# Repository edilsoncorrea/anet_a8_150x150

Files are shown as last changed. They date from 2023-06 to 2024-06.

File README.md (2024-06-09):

# anet_a8_150x150
Documentação para a criação da Impressora 3D baseada na Anet A8 de 150mm x 150mm

[Lista de peças](https://docs.google.com/spreadsheets/d/166N1_jKjehIjcxCUM2Ibk8MToJvCky88ICG7slx1OKs/edit#gid=0)

### Pinagem da minha montagem
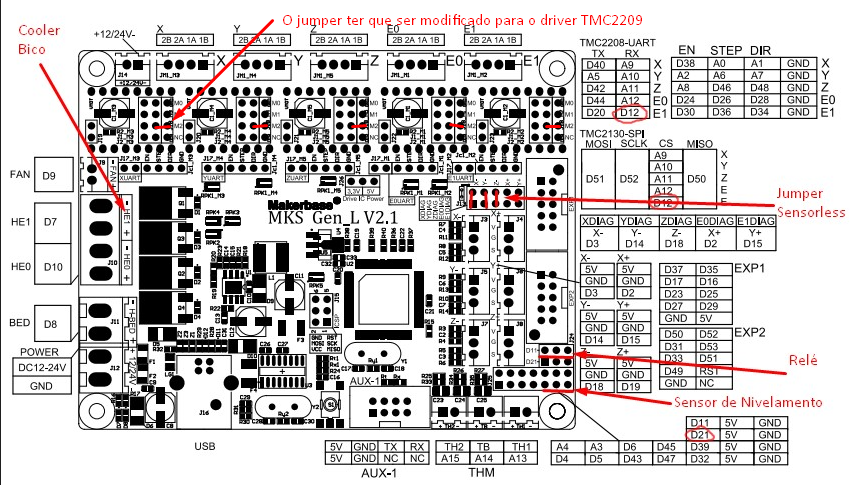
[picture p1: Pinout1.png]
Minha Montagem


Os motores precisarão ser invertidos quando trocar os drivers de DRV8825 para TMC2209

Os motores dos eixos deverão de ajustados para 600mA e o motor da extrusora para 960mA.

[Fork do Marlin para a Anet A8 Mini](https://github.com/edilsondsnerp/Marlin.git)

[MKS Gen L v21](https://github.com/edilsoncorrea/mksgenlv21.git)

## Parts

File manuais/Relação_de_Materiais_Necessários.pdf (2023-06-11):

Relação de Materiais Necessários

Estrutura de Aluminio V-Slot 20x20 | | Ferramentas Necessárias
3 Perfis com 320mm | Furadeira/Parafusadeira | Macho M3x0.5 | Chave Philips
4 Perfis com 350mm | Broca de Aço Rápido 2.5mm | Macho M6x1.0 | Alicate de Corte
8 Parafusos M6x30mm | Broca de Aço Rápido 3.0 mm | Broca de Aço Rápido 6.0 mm | Fita Hellerman
| Broca de Aço Rápido 5.0 mm | Fresa de Aço Rápido 11.0 mm | Chave Allen 3/16
Nome | Qtd de Peças Impressas | Tipo de Parafuso | Tamanho em mm | Qtd de Parafusos | Qtd de Porcas | Qtd de Arruelas
Fim de Curso Z - Base | 1 | M3 | 12 | 2 | 0 | 2
Fim de Curso Z - Móvel | 1 | M3 | 18 | 2 | 2 | 4
Tensionador da Correia Y - Base | 1 | M3 | 18 | 2 | 0 | 2
Tensionador da Correia Y - Móvel | 1 | M3 | 28 | 2 | 2 | 3
Suporte Placa Anet + Mosfet | 1* | M3 | 18 | 3 | 0 | 3
M3 | 8 | 8 | 0 | 0
Suporte Placa Anet | 1* | M3 | 18 | 3 | 0 | 3
| | M3 | 8 | 4 | 0 | 0
Suporte Placa Ramps | 1* | M3 | 18 | 3 | 0 | 3
| | M3 | 8 | 4 | 0 | 0
Suporte Placa Ramps + Mosfet | 1* | M3 | 18 | 3 | 0 | 3
M3 | 8 | 8 | 0 | 0
Base Suporte LCD | 2 | M3 | 18 | 2 | 0 | 2
| | M3 | 12 | 2 | 2 | 2
Suporte LCD Anet | 1* | M3 | 8 | 4 | 0 | 0
Suporte LCD Ramps 2004 SD | 1* | M3 | 8 | 4 | 0 | 0
Suporte Conector Tomada | 1** | M3 | 18 | 2 | 0 | 2
Suporte Motor Y | 1 | M3 | 18 | 2 | 0 | 2
M3 | 8 | 3 | 0 | 3
Suporte Motor Z | 2 | M3 | 18 | 3 | 0 | 3
M3 | 8 | 4 | 0 | 4
Trava Superior Z Esquerda | 1 | M3 | 18 | 2 | 0 | 2
Trava Superior Z Direita | 1 | M3 | 18 | 2 | 0 | 2
Trava Guia Linear Y Direita | 2 | M3 | 18 | 4 | 0 | 4
Trava Guia Linear Y Esquerda | 1 | M3 | 18 | 2 | 0 | 2
Trava Guia Linear Y Fim de Curso | 1 | M3 | 18 | 2 | 0 | 2
Trava da Fonte de Alimentação | 0 | M3 | 18 | 2 | 0 | 0
* - Escolher o modelo e imprimir apenas o correto
Quantidade de Parafusos | | ** - Imprimir apenas se tiver a peça necessária
M6x30mm | 8
M3x8mm | 19 | Peças necessárias que deverão ser compradas por fora
M3x12mm | 4 | 4 x Pézinhos M6 Emborrachados
M3x18mm | 30
M3x28mm | 2
Porcas M3 | 6
Arruelas M3 | 53

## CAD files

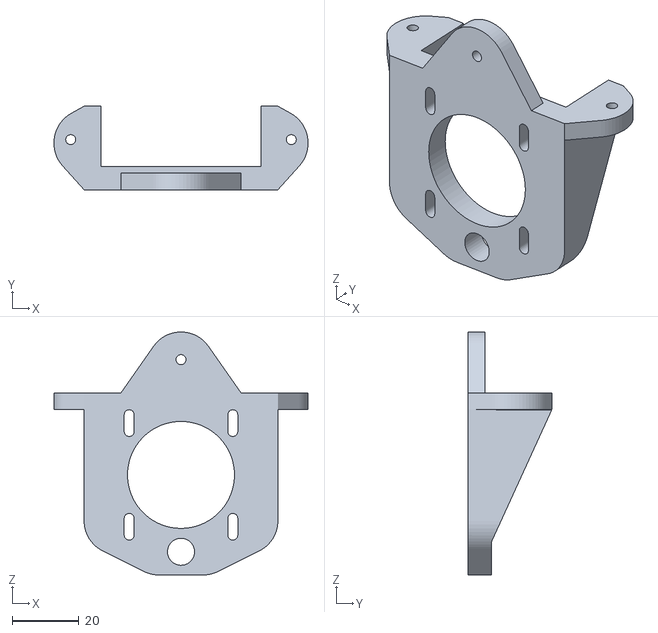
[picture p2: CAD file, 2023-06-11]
stl/Suporte_Motor_Z_v10.stl
76.0 x 25.0 x 72.7

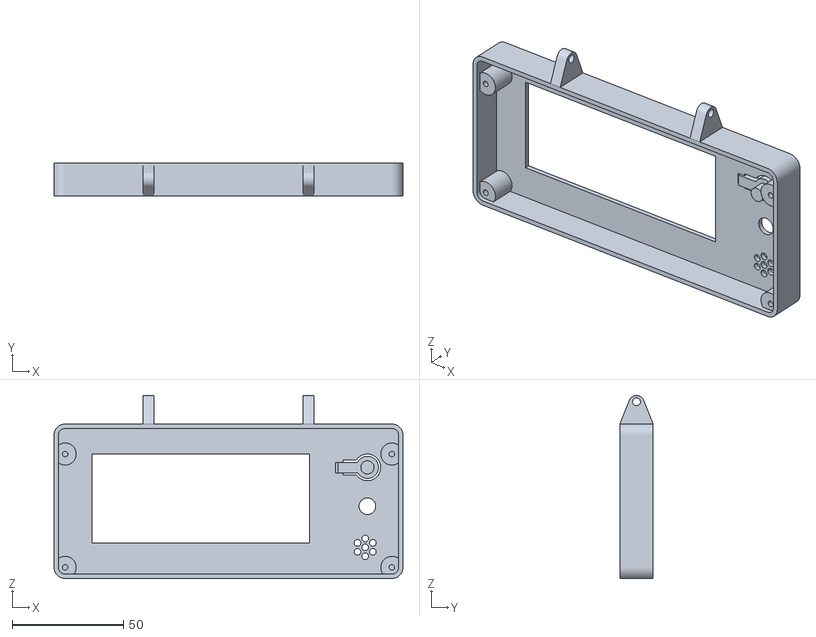
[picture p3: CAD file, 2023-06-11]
stl/Suporte_LCD_Ramps_2004_SD_v7.stl
157.0 x 15.0 x 82.3

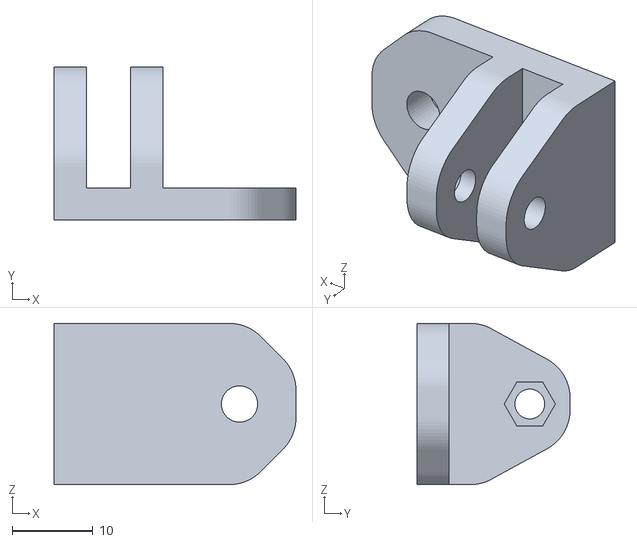
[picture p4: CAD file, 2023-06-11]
stl/Base_Suporte_LCD_v1.stl
30.0 x 19.0 x 20.0

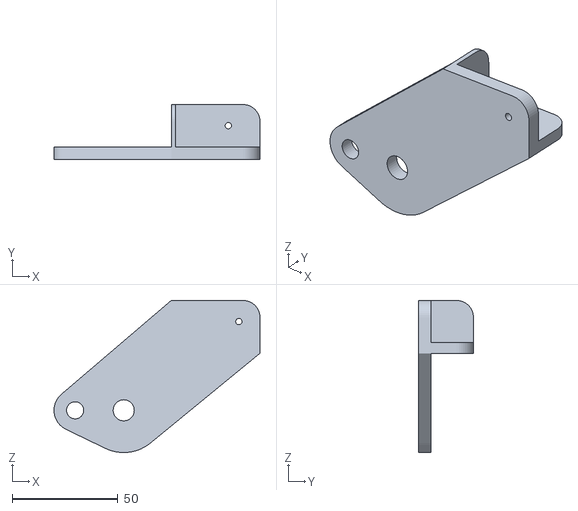
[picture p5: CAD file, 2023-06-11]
stl/Suporte_Superior_Z_Esquerda_v11.stl
97.5 x 26.0 x 72.0

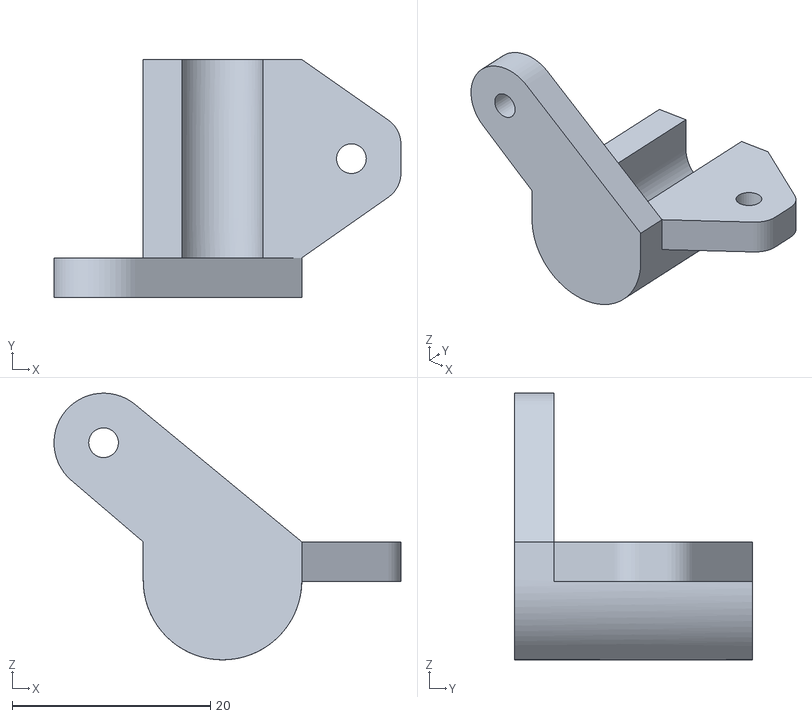
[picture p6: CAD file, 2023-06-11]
stl/Trava_Guia_Linear_Y_Direita_v2.stl
35.0 x 24.0 x 26.9

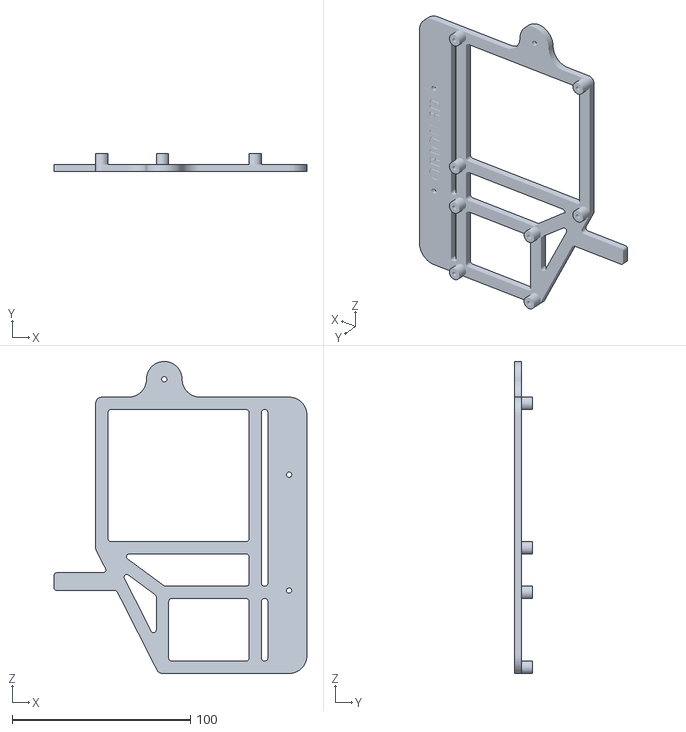
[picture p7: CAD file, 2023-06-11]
stl/Suporte_Placa_Anet_+_Mosfet_v7.stl
141.8 x 10.0 x 175.0

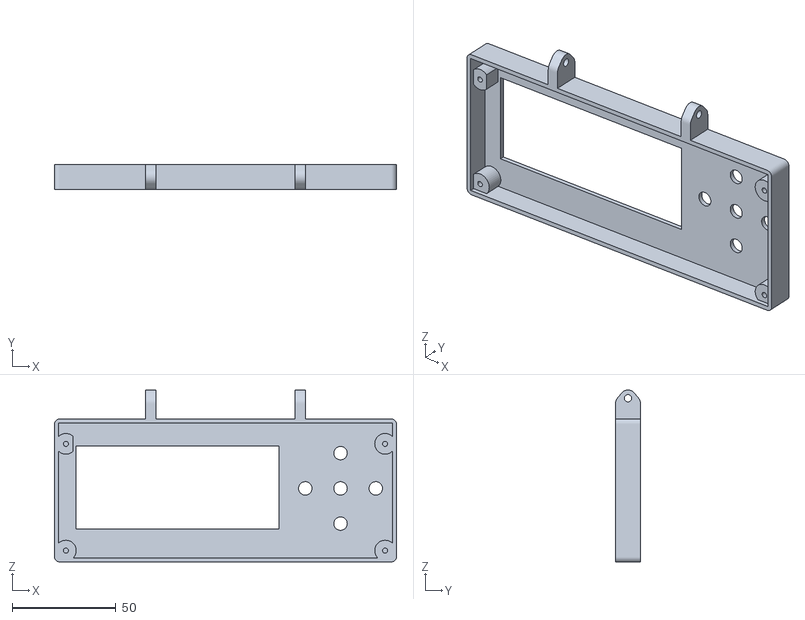
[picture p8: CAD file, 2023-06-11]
stl/Suporte_LCD_Anet_v5.stl
165.0 x 12.0 x 83.0

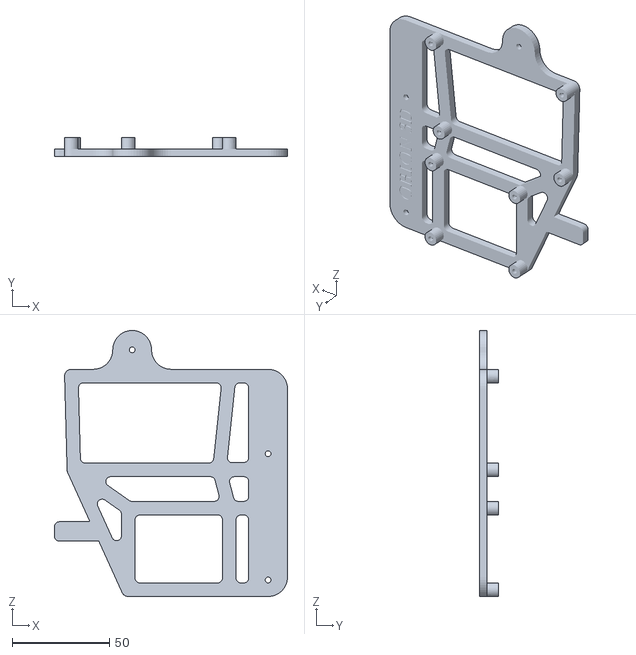
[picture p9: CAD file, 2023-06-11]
stl/Suporte_Placa_Ramps_+_Mosfet_v10.stl
120.0 x 10.0 x 137.0

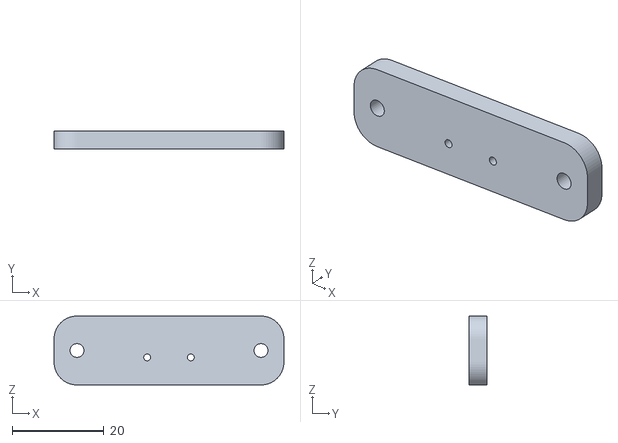
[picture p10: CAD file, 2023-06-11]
stl/Fim_de_Curso_Z_-_Móvel_v3.stl
50.0 x 4.00 x 15.0

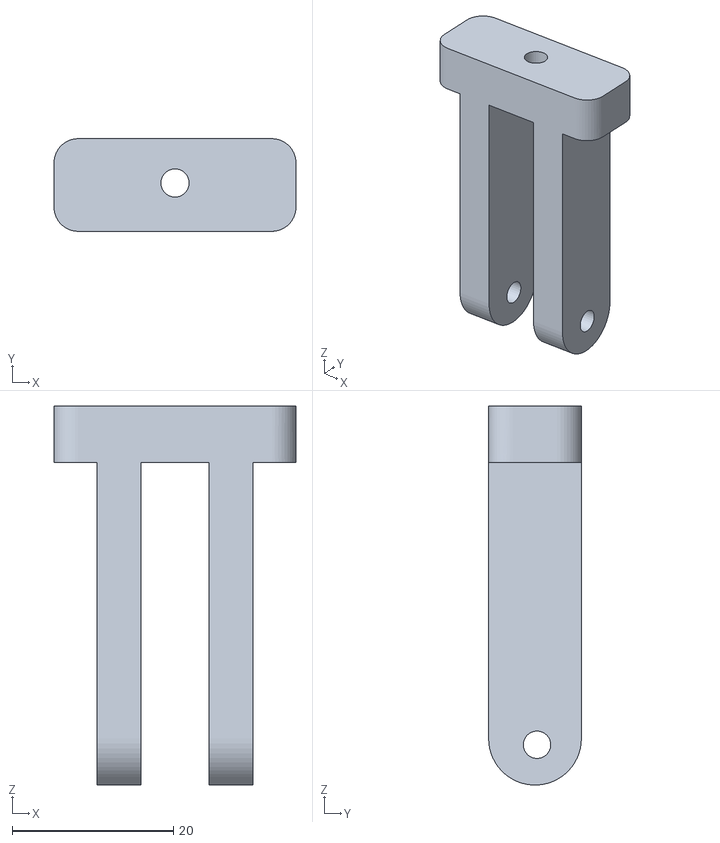
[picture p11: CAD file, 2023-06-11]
stl/Tensionador_da_Correia_Y_-_Móvel_v3.stl
30.0 x 11.5 x 47.0

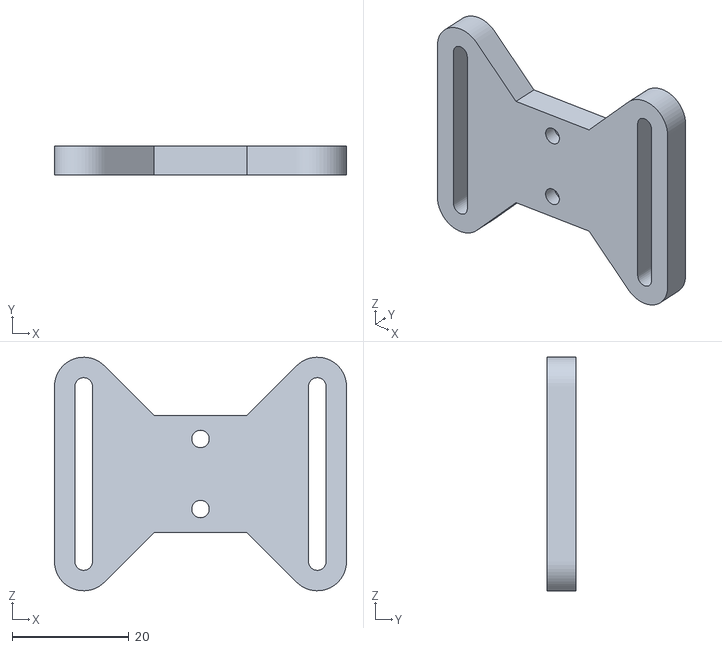
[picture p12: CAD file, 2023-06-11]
stl/Fim_de_Curso_Z_-_Base_v2.stl
50.0 x 5.00 x 40.0

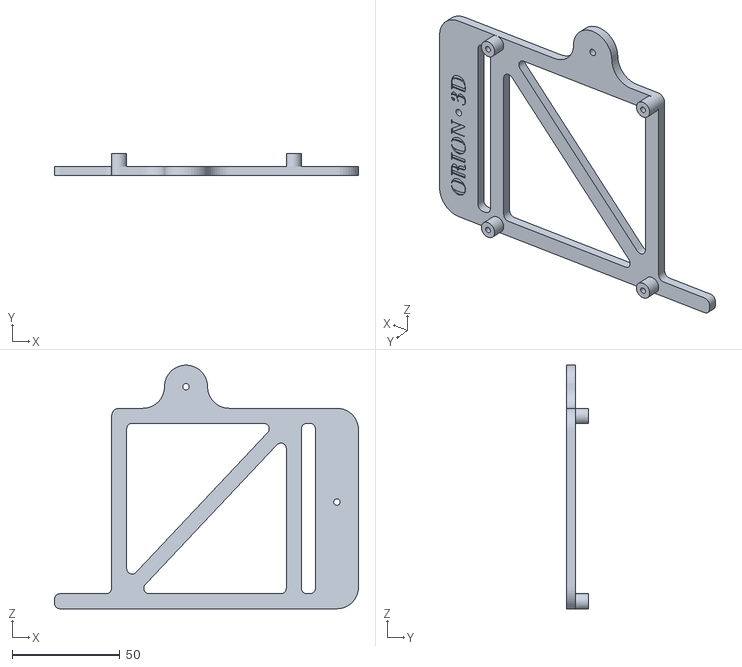
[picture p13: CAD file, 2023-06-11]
stl/Suporte_Placa_Anet_v9.stl
141.0 x 10.0 x 113.0

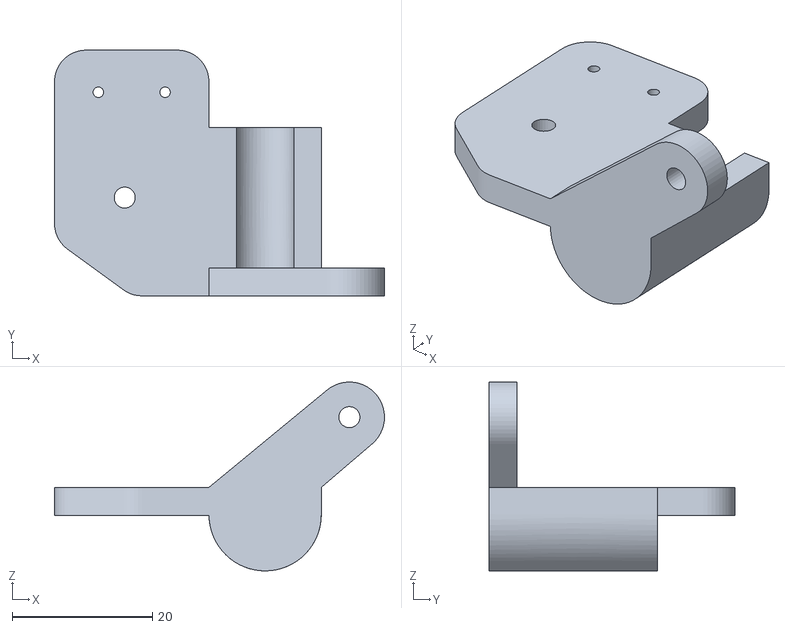
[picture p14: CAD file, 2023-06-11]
stl/Trava_Guia_Linear_Y_Fim_de_Curso_v3.stl
47.0 x 35.0 x 26.9

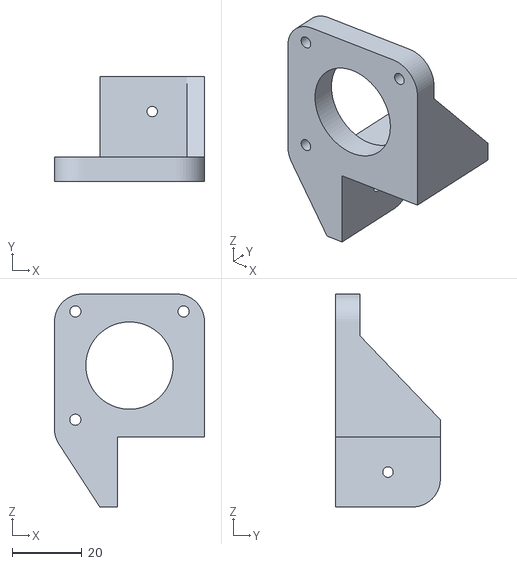
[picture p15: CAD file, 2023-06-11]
stl/Suporte_Motor_Y_v6.stl
43.0 x 30.0 x 61.0

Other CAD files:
stl/Suporte_Superior_Z_Direita_v9.stl
stl/Trava_Guia_Linear_Y_Esquerda_v3.stl
stl/Suporte_Placa_Ramps_v6.stl
stl/Tensionador_da_Correia_Y_-_Base_v6.stl
sketchup/Suporte_Motor_Y_v6.skp
sketchup/Tensionador_da_Correia_Y_-_Móvel_v3.skp
sketchup/Tensionador_da_Correia_Y_-_Móvel_v4.skp
sketchup/l.skp
stl/Suporte_Conector_Tomada_v4.stl

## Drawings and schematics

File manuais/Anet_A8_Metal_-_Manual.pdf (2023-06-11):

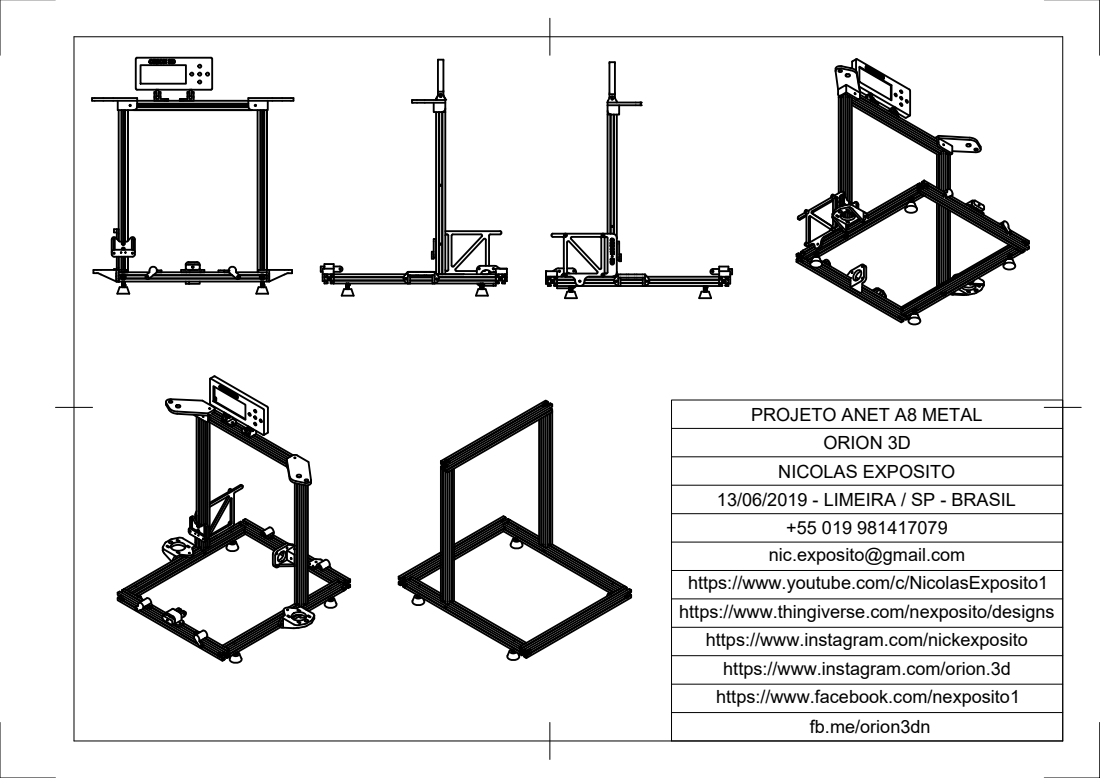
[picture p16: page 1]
NICOLAS EXPOSITO; ORION 3D

PROJETO ANET A8 METAL

13/06/2019 - LIMEIRA / SP - BRASIL

nic.exposito@gmail.com

https://www.youtube.com/c/NicolasExposito1
https://www.thingiverse.com/nexposito/designs
https://www.instagram.com/nickexposito
https://www.instagram.com/orion.3d
https://www.facebook.com/nexposito1

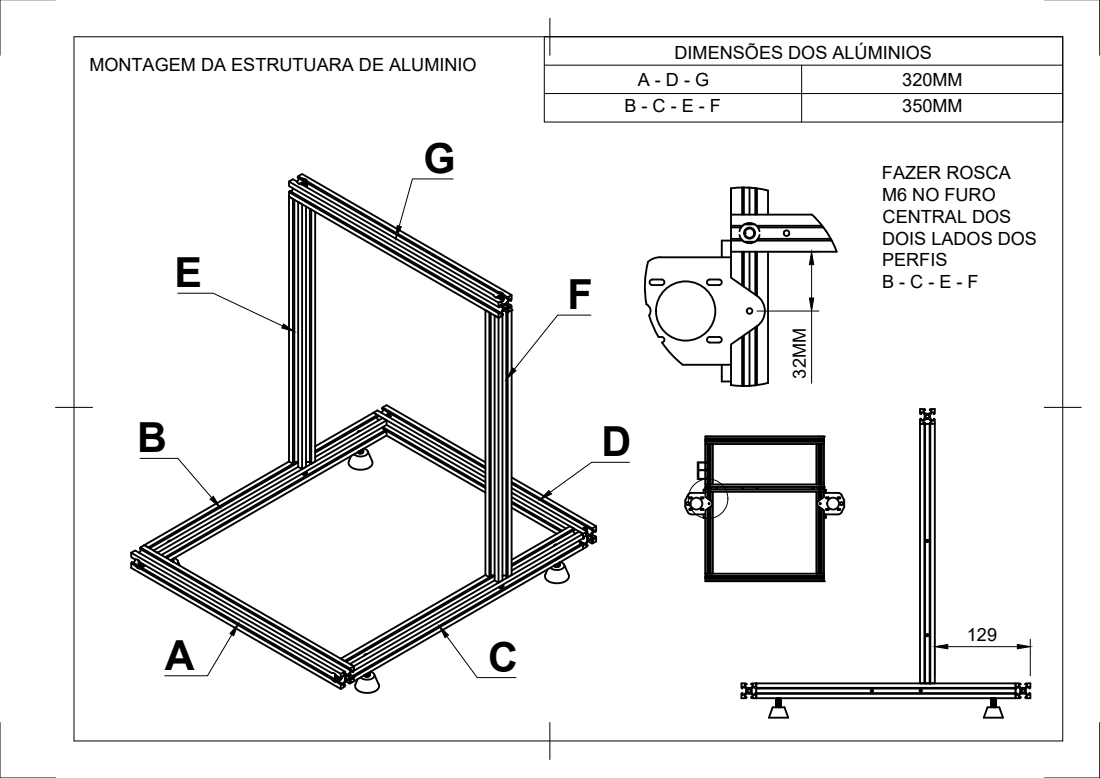
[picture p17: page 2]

DIMENSÕES DOS ALÚMINIOS

MONTAGEM DA ESTRUTUARA DE ALUMINIO

A - D - G | 320MM
B - C - E - F | 350MM

FAZER ROSCA
M6 NO FURO
CENTRAL DOS
DOIS LADOS DOS
PERFIS

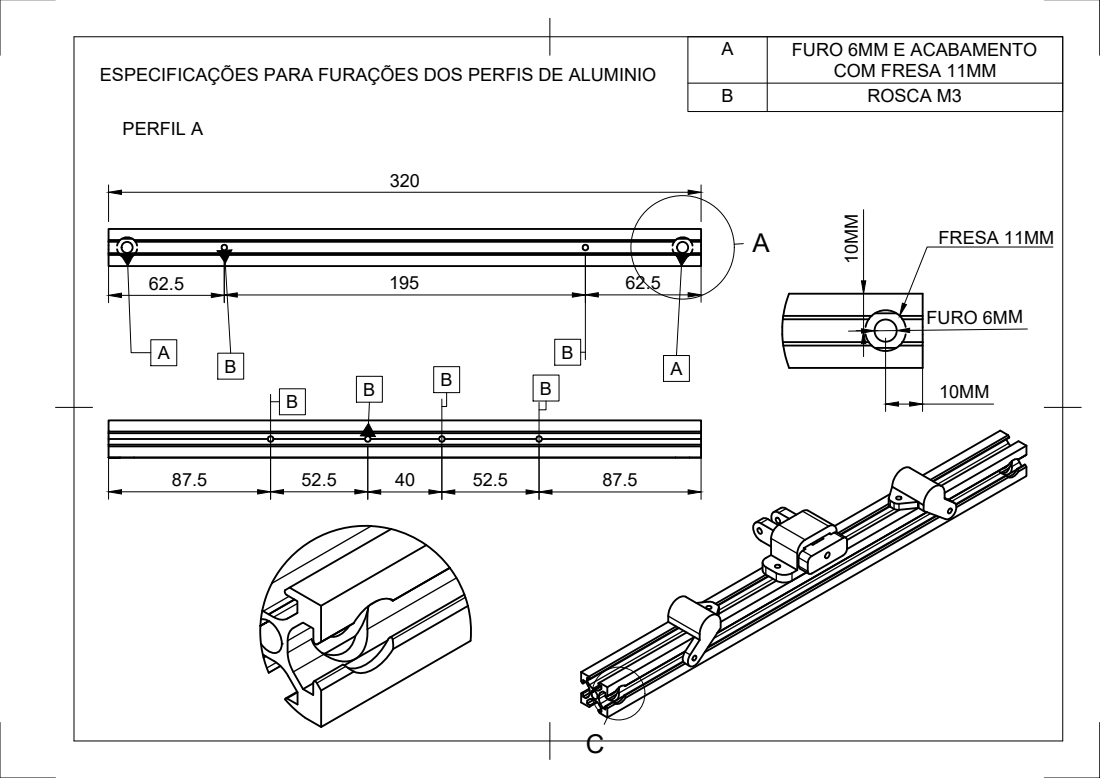
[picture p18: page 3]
FURO 6MM; FRESA 11MM 10MM

PERFIL A 320 | A | FURO 6MM E ACABAMENTO COM FRESA 11MM

ESPECIFICAÇÕES PARA FURAÇÕES DOS PERFIS DE ALUMINIO

B | ROSCA M3

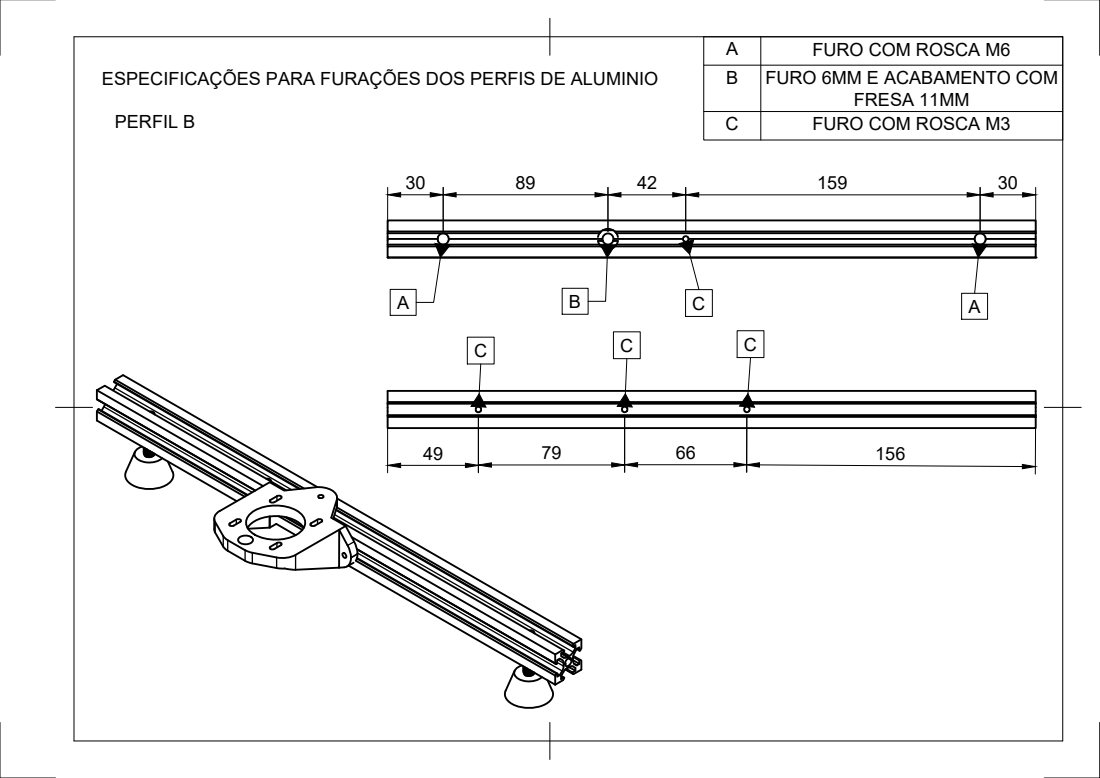
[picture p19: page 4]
PERFIL B; FURO COM ROSCA M6

ESPECIFICAÇÕES PARA FURAÇÕES DOS PERFIS DE ALUMINIO

B | FURO 6MM E ACABAMENTO COM FRESA 11MM

C | FURO COM ROSCA M3

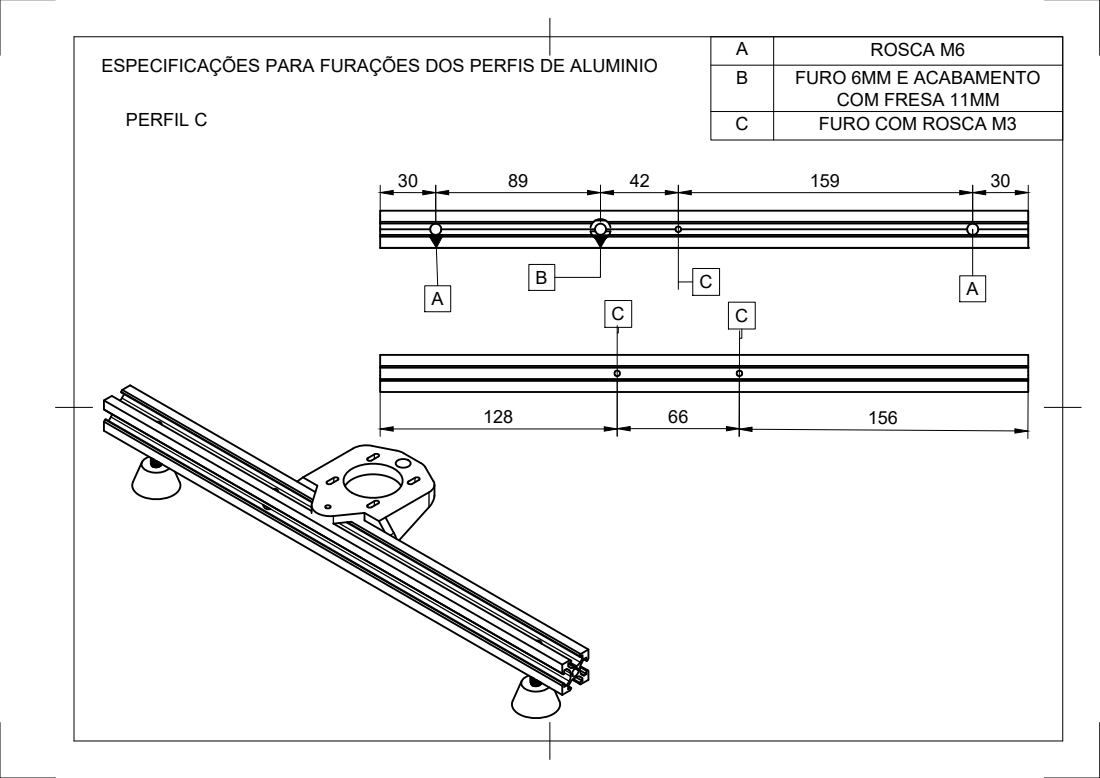
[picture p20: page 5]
PERFIL C; ROSCA M6

ESPECIFICAÇÕES PARA FURAÇÕES DOS PERFIS DE ALUMINIO

B | FURO 6MM E ACABAMENTO COM FRESA 11MM

C | FURO COM ROSCA M3

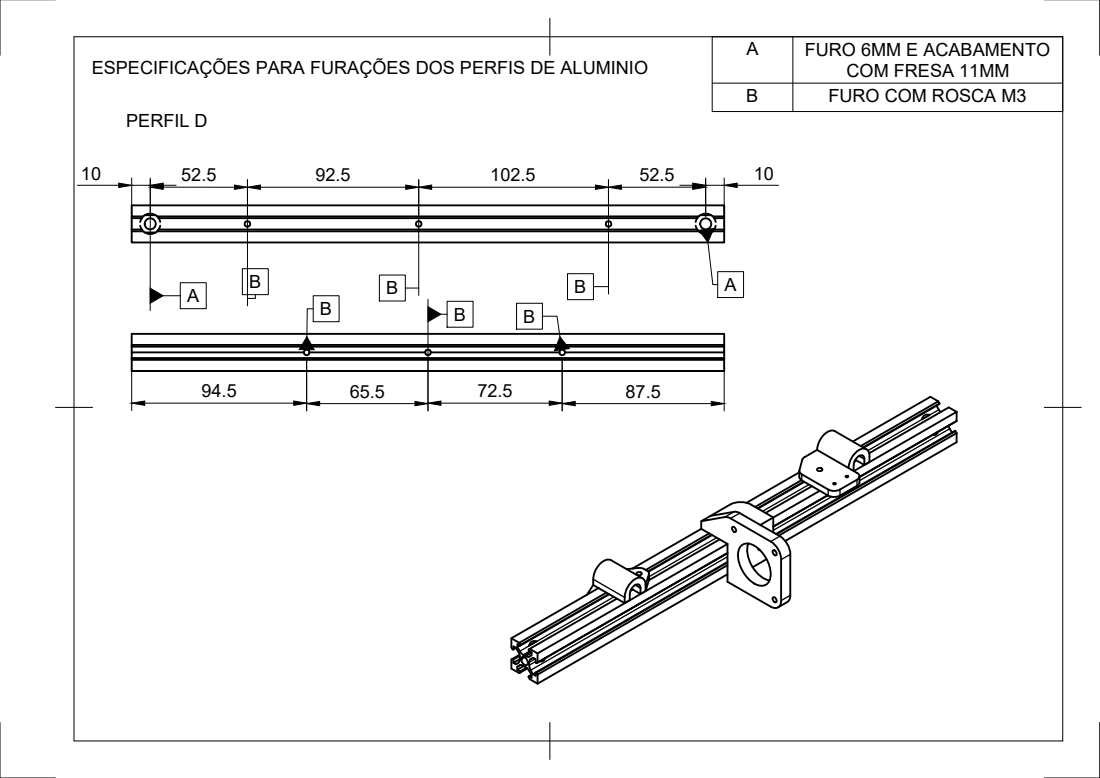
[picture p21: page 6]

PERFIL D | A | FURO 6MM E ACABAMENTO COM FRESA 11MM

ESPECIFICAÇÕES PARA FURAÇÕES DOS PERFIS DE ALUMINIO

B | FURO COM ROSCA M3

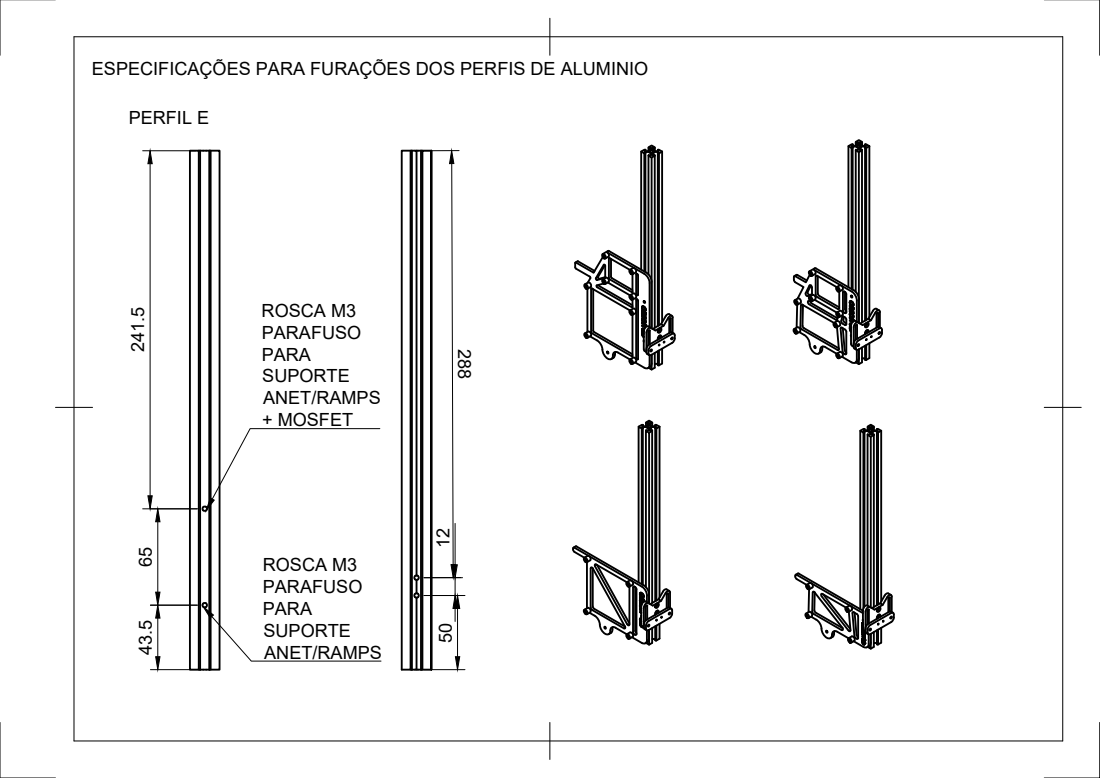
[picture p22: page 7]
ESPECIFICAÇÕES PARA FURAÇÕES DOS PERFIS DE ALUMINIO 43.5 65 241.5; ROSCA M3; + MOSFET; PERFIL E

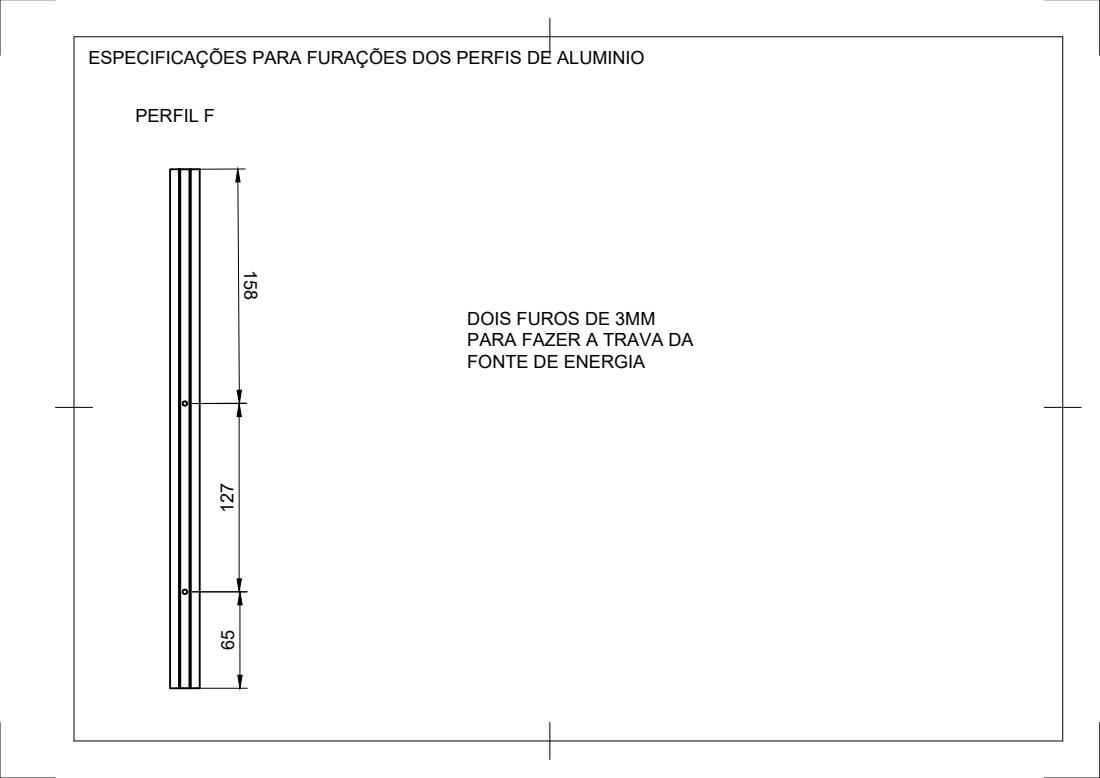
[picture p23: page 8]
PERFIL F

ESPECIFICAÇÕES PARA FURAÇÕES DOS PERFIS DE ALUMINIO

DOIS FUROS DE 3MM
PARA FAZER A TRAVA DA
FONTE DE ENERGIA

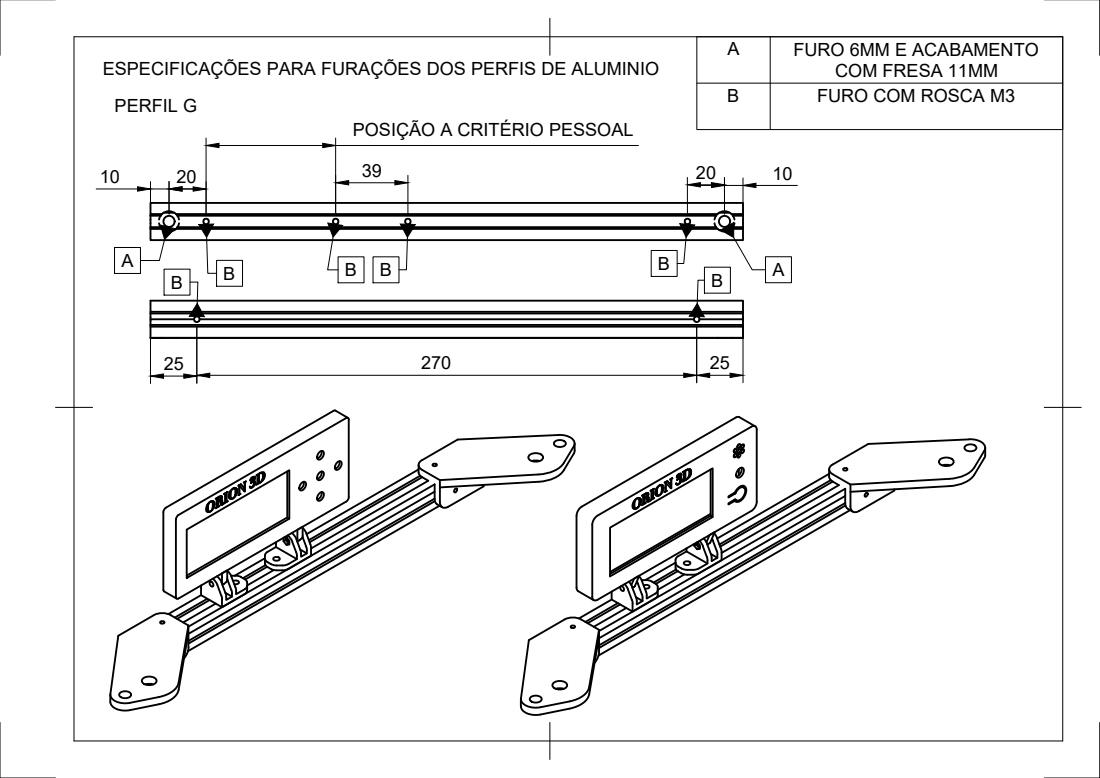
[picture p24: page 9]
PERFIL G

A | FURO 6MM E ACABAMENTO COM FRESA 11MM

ESPECIFICAÇÕES PARA FURAÇÕES DOS PERFIS DE ALUMINIO

B | FURO COM ROSCA M3

POSIÇÃO A CRITÉRIO PESSOAL
